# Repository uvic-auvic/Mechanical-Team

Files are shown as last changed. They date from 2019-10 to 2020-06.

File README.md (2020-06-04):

# AUVIC Mechanical Repository

Welcome to the mechanical team. One rule: do not push directly into master. Please talk with the lead if you dont understand why.

## Getting started (bottom up)

We use solidworks prolifically in this university. I will assume everyone is using a windows machine. Before continuing, please make a [github](https://github.com/) account.  

- Go to [gitforwindows.org](https://gitforwindows.org/) to download git. Follow instalation guidelines but enable "use git from the command line"
- After completing the installation, open CMD (shortcut: WIN+R , enter 'cmd') and enter these two commands
    - git config --global user.name "*your name*"
    - git config --global user.email "*github email*"
- Next we want to clone the repository:
    - Open cmd and in your user directory, type "*mkdir auvic*"
    - Type "cd auvic"
    - In the mechanical team repository, click the green "clone or download" button and copy the address.
    - Type "git clone https://github.com/uvic-auvic/Mechanical-Team.git *name_of_folder*"

You are ready to go (but not really).

## Really getting started

Before you rush into a project there is one major rule that must be followed at all times:

**Do not push directly into master**

Now that you have a copy of the repository on your device, it is yours. Nobody but you can edit it's contents. But there is a procedure that must be followed before beginning and finishing a project, which is branching.

### What is branching?

Branching is the way how multiple people can be working in one project and not impede one another. If everyone worked in a single branch, you will find some files moved, disabled, or deleted everytime someone pushes to the remote repo. In large projects, this makes work much more difficult. This is why clever people created branching, basically having two "timelines" of the same project that merge once the project manager accepts the changes.

In the case of no branching, say Evan was working on the main enclosure assembly of the submarine and decided to use a part that Peyton originally made for the frame. At first everything is fine, but after a little while later Peyton finds the frame design is fundamentally incorrect and deletes all his files and update the remote repo. Evan, seeing the repo being updated, pulls a fresh copy. All of sudden, parts randomly disapeared from his assembly. After several hours of checking the folders for the missing parts with no luck, he decides to remake them ground up; wasting time and energy. 

Using branching, Peyton and evan would be working on their own branches, while the master branch stays clean and only contains reviewed and approved parts. Any pushes Peyton makes would only affect his branch and Evan can complete his work safely.

### How to switch branches

To switch into different branches, you will need to use the keyword *checkout*. First check the current list of branches and choose the one you want to download locally. See the list of common git commands below to download and switch branches.

- Check the current list of branches: "git branch -a"  
- Download a remote branch: "git checkout *name_of_branch*"
- To peek at the contents of a branch: "git checkout origin/*name_of_branch*"
- To make your own branch and checkout into it: "git checkout -b *name_of_branch*"
    - Creating a local branch and pushing it into a remote repository is a more involved and much more than I expect from a mechanical student. I prefer you create the branches on the web client rather than on the command line, if needed.

After switching into your branch, you can now begin.

## Saving your work on the local repository

There are two ways you can save your work: committing and stashing. There isnt really any rules following commiting and stashing, but my only concern is dont *commit* an incomplete part. If for any reason you need to switch branches to work on another project, you should *stash* your work. A commit is basically a save point, in case you mess up bad, you want to be able to return to your last working copy of your project. An example where you would stash rather than commit is if you didnt finish building a part and you needed to switch projects.

You can stash multiple time and also on different branches. Here are a list of some commands:

- To stash your work: "git stash"
- To view all your stashes: "git stash list"
- To retrieve your stash: "git stash apply"
- to retrieve a specific stash: 
    - Get its name with "git stash list"
    - use "git stash apply *stash@{2}*"
- To commit your work: 
    - navigate to the repo
    - git add *
    - git commit -m "*enter message here*"
    **NOTE:** files need to be "Staged" to be commited by using the *add* command. 

## Pushing your work to the rmeote repository/branch

After you commited your work. Use the command: "git push" and that is it.

## After completing your assembly

Use the command: "git pull-request" for the lead to review your assembly. 
Now repeat.

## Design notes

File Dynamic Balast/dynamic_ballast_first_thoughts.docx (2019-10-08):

# Dynamic Ballast - Initial Thoughts

Bob Noakes
October 2, 2019

In order to reduce the constant vertical thrusting requirement for the UAV, it was proposed that a dynamic ballast system be conceptualized/designed. This would allow the vessel to submerge and surface by changing the ballast tank between air and water fill.

# Functional Requirements

- Submerge at the beginning of the run from surface to 10ft (3m) below water level
- Complete submerge operation in ??? seconds
- Remain submerged throughout the 30 minute trial period
- Surface at the end of the trial period
- Complete surfacing operation in ??? seconds
- Fit inside/on the submarine vessel and not interfere with the vessel operation
- Not pose a safety or damage risk from rupturing
- Others?

# Theory

The vessel size and mass should be designed to be approximately neutrally buoyant with the ballast tanks ~50% filled with water. The main variable affecting the magnitude of the submerging/surfacing force is the volume of the ballast tank.

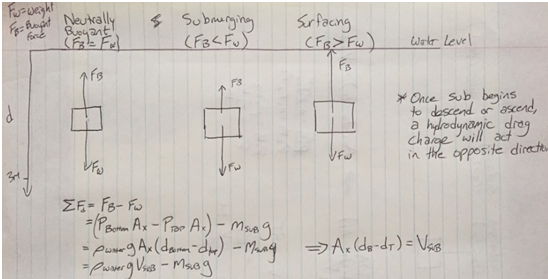
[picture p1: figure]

# Proposed operation

The buoyant force is equal to the weight of the displaced water. The system must be smart enough to fill up enough ballast to submerge at the desired speed, then partially purge to attain neutral buoyancy once the vessel reaches the target depth.

Surfacing is initiated by further or complete purging of water from the ballast tank. There must be enough pressure in the air tank to overcome hydrostatic pressure at the target depth and purge the water volume with a safety factor.

Here is a sample calculation with theoretical values. A 3L ballast tank provides a ~30N force window (15 for submerging, 15 for surfacing).

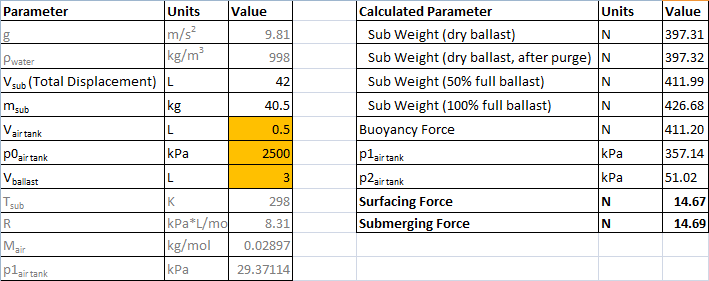
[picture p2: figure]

# Actions

- Find out what the hydrodynamic drag is at the required submerging/surfacing speed, determine size of ballast tankrequired
- Figure out what tank is the best option to contain the pressurized air
- Design a valve arrangement and control system
- Fit the tank into the vessel design

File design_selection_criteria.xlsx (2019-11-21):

Feature | Sub-Feature | Weight | Design 1 Score | Design 2 Score | Design 3 Score
Gate navigation | Passes through | 100
 | Maintains fixed heading | 150
 | Coin flip | 300
 | Pass through 60% Section | 200
 | Pass through 40% Section | 400
 | Style | 800
Picking up objects | Crucifix | 400
 | Garlic | 400
Follows "path" |  | 200
Slaying vampires | Any | 300
 | Called | 300
Drop garlic | Open | 1400
 | Closed | 600
 | Move Arm | 400
Stake through heart | open oval, cover oval, Sm Heart | 2400
 | move lever | 400
 | Bonus: cover oval, Sm heart | 500
Expose to sunlight | Surface in area | 1000
 | surface with object
 | open coffin | 400
 | drop pickup | 200
Random Pinger first task |  | 500
Random Pinger second task |  | 1500
Inter vehicle communication |  | 1000
Minutes Leftover |  | 100
Website |  | 50
Technical Merit |  | 150
Written Style |  | 50
Static Judging - capability |  | 100
Creativity |  | 100
Team Uniform |  | 10
Team Video |  | 50
Pre-qualification |  | 100
Discretionary static points |  | 40
TOTALS

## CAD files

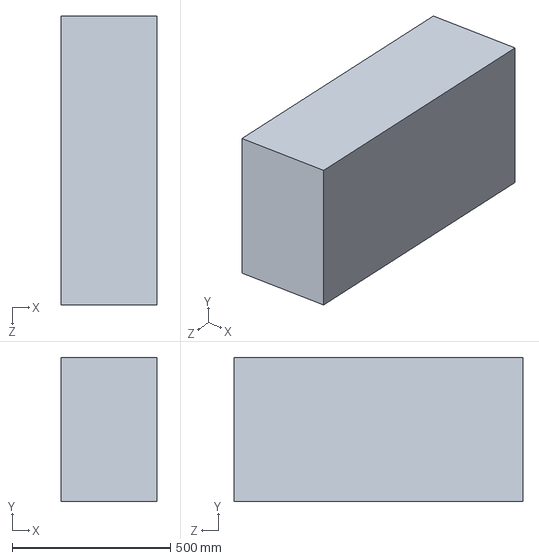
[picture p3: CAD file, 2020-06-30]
frame/demonstration/PART_MODEL_mainenclosure.SLDPRT
304.8 x 457.2 x 914.4 mm

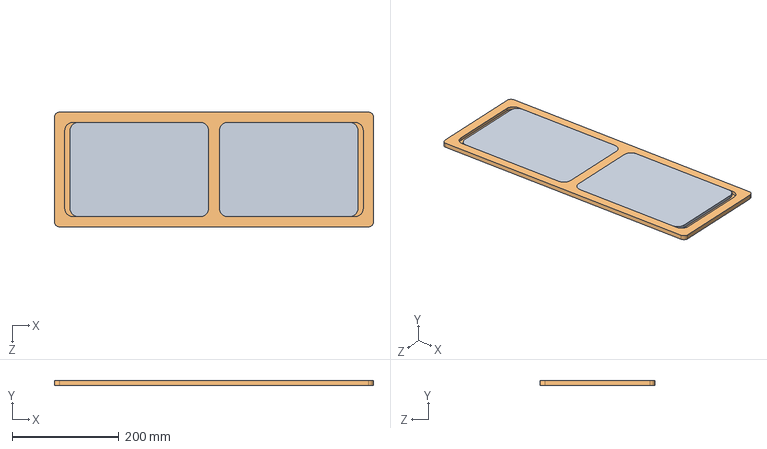
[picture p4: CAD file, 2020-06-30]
lobsta_concept_CAD/auv_assemblies/shell_rect_assembly.sldasm
599.0 x 9.00 x 215.4 mm
Lid_window x 2
lid_rectangular

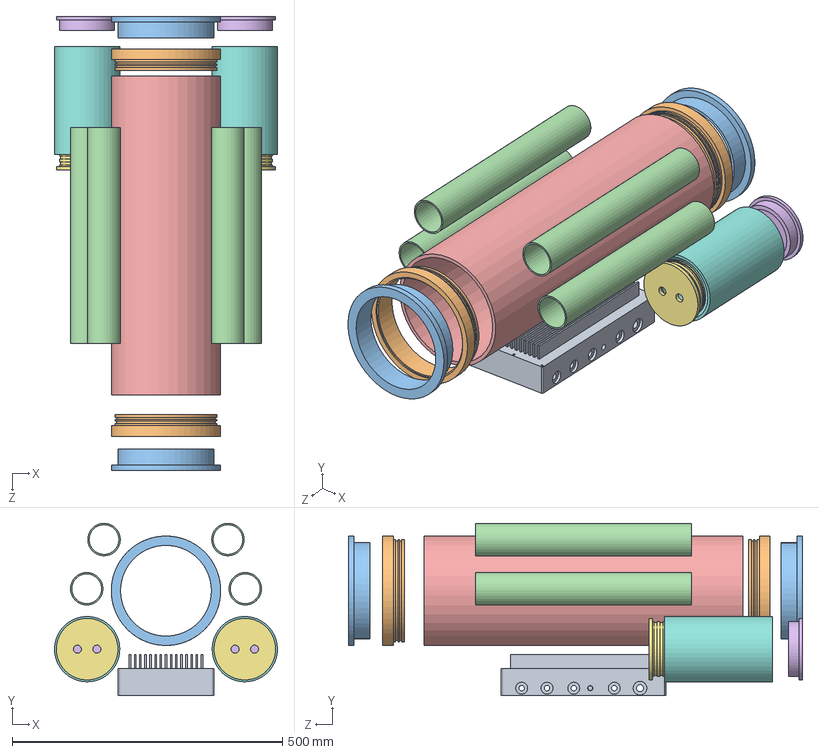
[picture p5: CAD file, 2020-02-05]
lobsta_concept_CAD/shell_assembly.SLDASM
412.7 x 319.1 x 840.6 mm
PN220301_Rev3 - Main
end_housing x 2
end_cap x 2
Pontoon x 4
inner_main_shell
cap_fixed x 2
cap_remove x 2
housing x 2

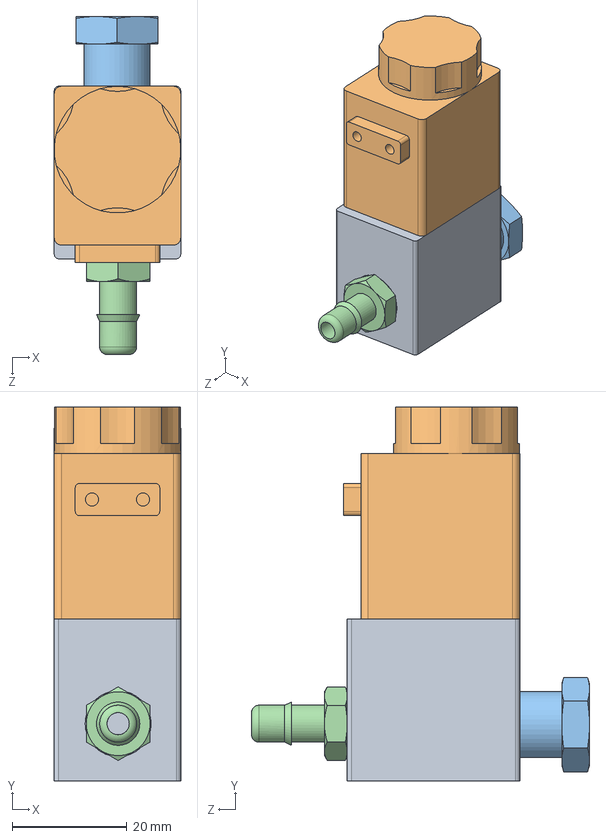
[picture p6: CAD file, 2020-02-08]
lobsta_concept_CAD/solenoid_valve/Solenoid Valve Assembly REV1.SLDPRT.SLDASM
22.0 x 65.1 x 58.9 mm
Solenoid Valve bottom REV1
Solenoid Valve Top REV1
Brass Adapter
5058K294_ALUMINUM BARBED TUBE FITTING

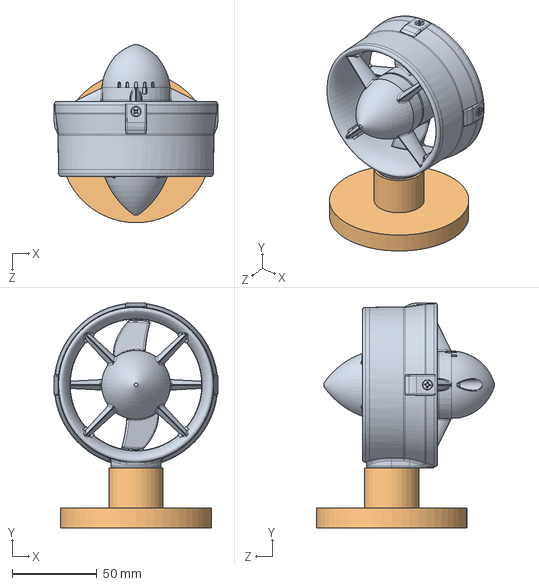
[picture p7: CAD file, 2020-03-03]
lobsta_concept_CAD/thrusters/thruster_assem.SLDASM
96.6 x 132.8 x 105.3 mm
T100-ASM-CW-THRUSTER-R1
thruster_bracket

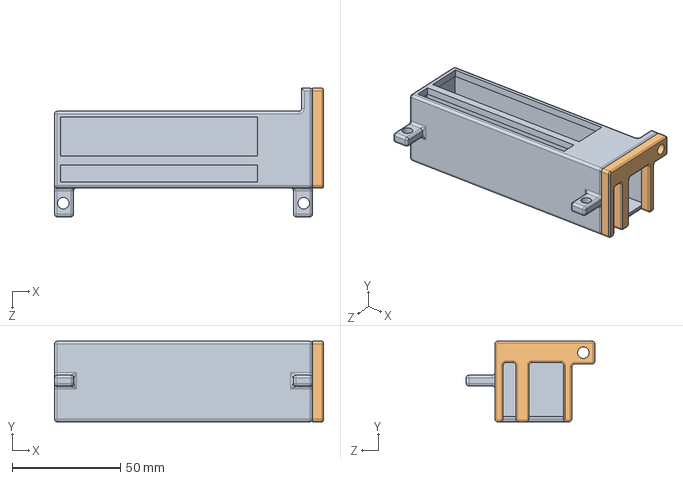
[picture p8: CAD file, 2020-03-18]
lobsta_concept_CAD/usb_hub/USB-holder-assy-v2.SLDASM
124.5 x 37.3 x 59.6 mm
USB-holder-box-v4
USB-holder-cover-v2

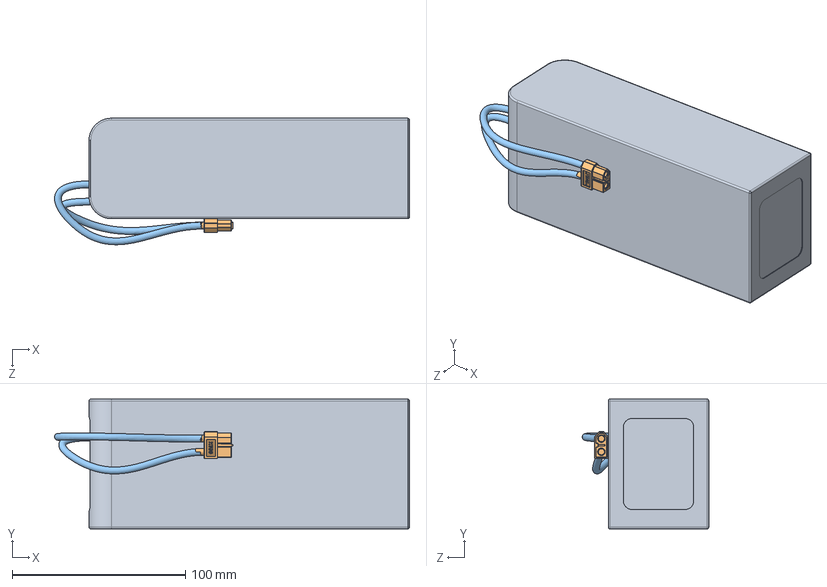
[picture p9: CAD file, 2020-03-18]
lobsta_concept_CAD/battery/Assembly_Multistar_Battery_3000mah.SLDASM
204.9 x 75.0 x 73.1 mm
Multistar_3000mAh_4S_Lipo_Battery
XT60 Buchse
Part3^Assembly_Multistar_Battery_3000mah

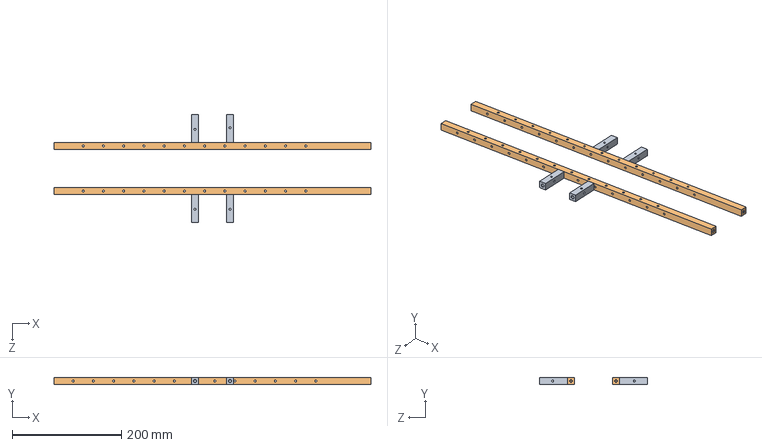
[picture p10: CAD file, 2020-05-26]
lobsta_concept_CAD/frame/frame_assembly.sldasm
581.0 x 12.7 x 197.4 mm
barstock support_short x 4
barstock support_long x 2

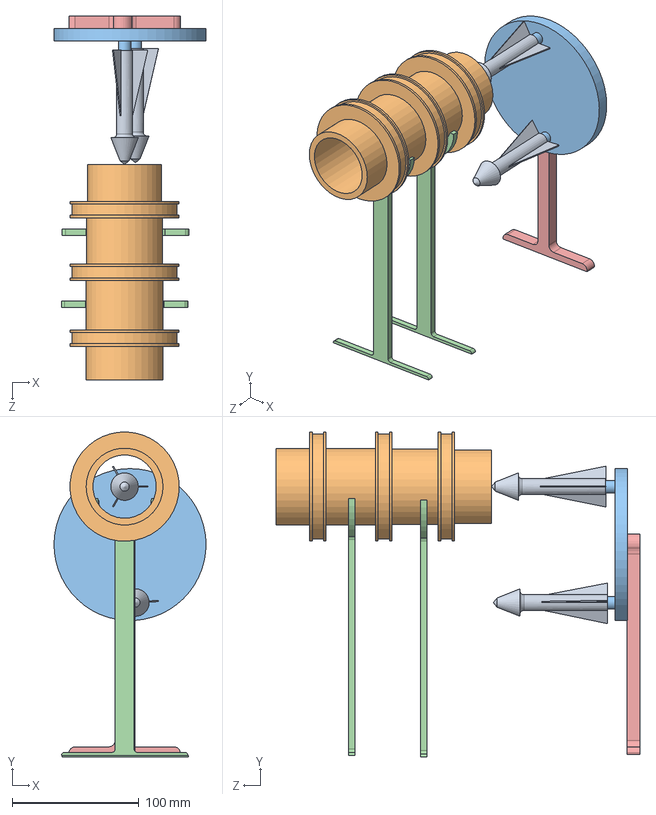
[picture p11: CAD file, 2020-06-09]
Torpedos/Assembly_torpedo-system1.SLDASM
119.9 x 256.6 x 287.0 mm
torpedo x 2
barrel
gattling disk
barrel_stand x 2
gattling_stand

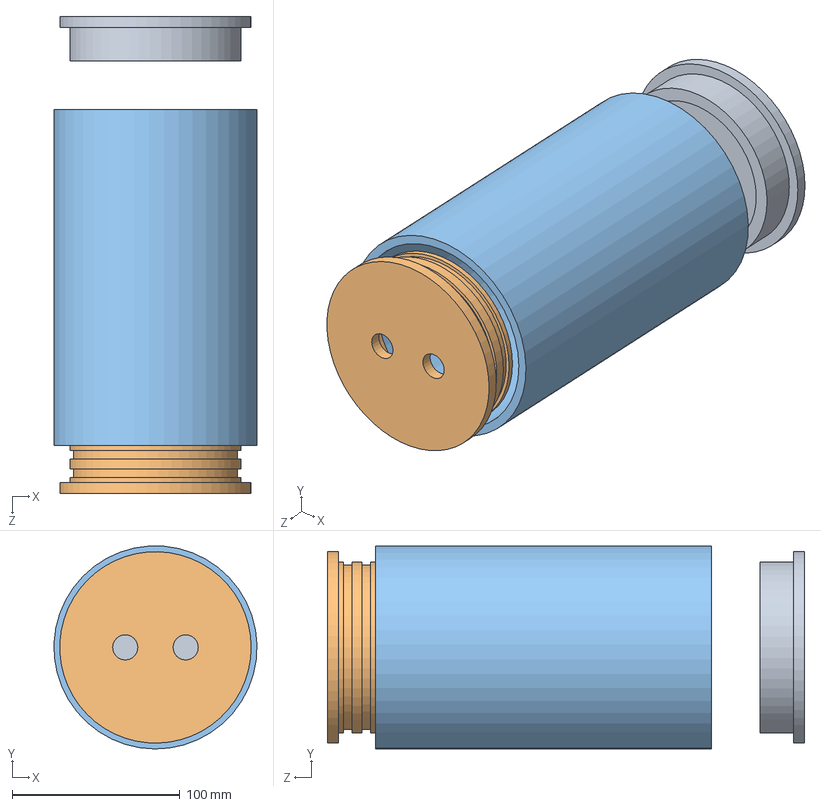
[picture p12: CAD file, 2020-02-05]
lobsta_concept_CAD/battery assembly/battery_assembly1.SLDASM
120.9 x 120.9 x 284.1 mm
cap_fixed
cap_remove
housing

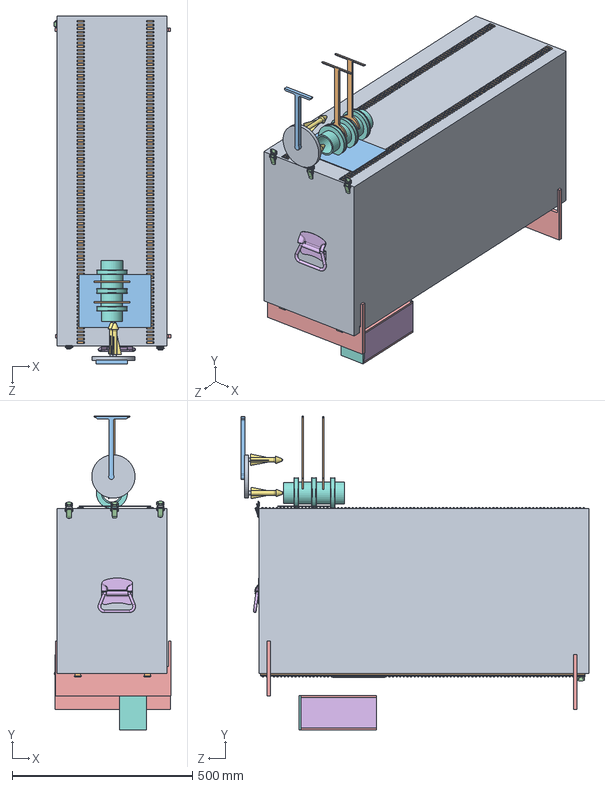
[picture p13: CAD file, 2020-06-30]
frame/demonstration/ASSEM_Frame.SLDASM
323.4 x 870.6 x 963.6 mm
PART_MODEL_mainenclosure
PART_PicRail x 4
PART_PeriphMount x 2
6082A120_DRAW LATCH x 4
stand x 2
TCH-500-1335802
torpedo x 2
barrel
gattling disk
barrel_stand x 2
gattling_stand
AUVIC ArcScrew 1stDraft
Top Bottom cap x 2
Side Plate x 2
BALL x 2
Back Plate

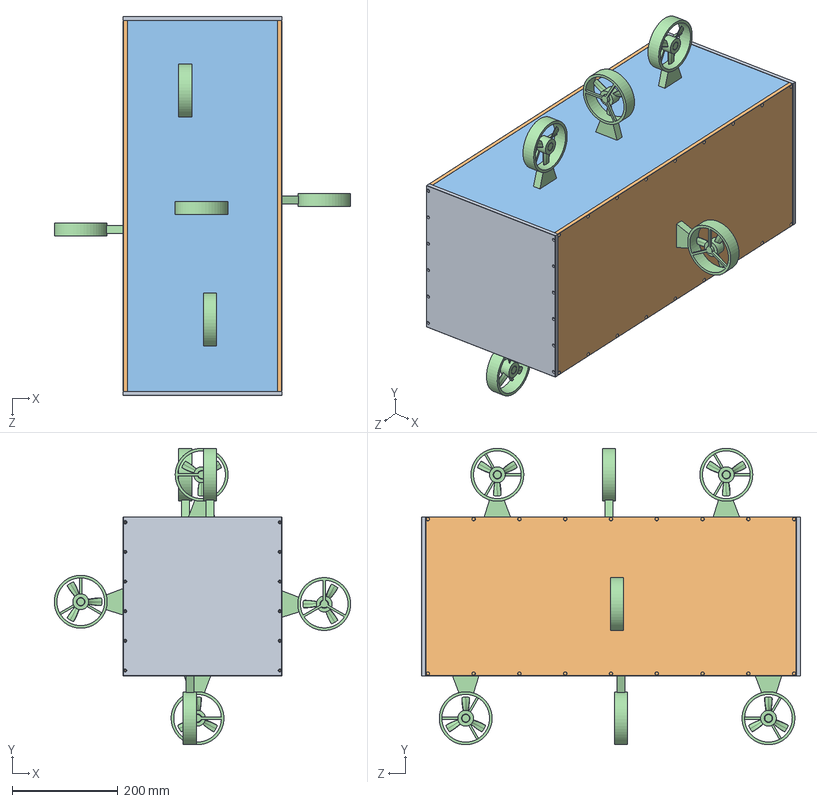
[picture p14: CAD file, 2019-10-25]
Mockup Drawings/square_sub/square_assem.SLDASM
560.0 x 560.0 x 716.0 mm
back_plate x 2
side_plate x 2
top_plate x 2
thruster x 8

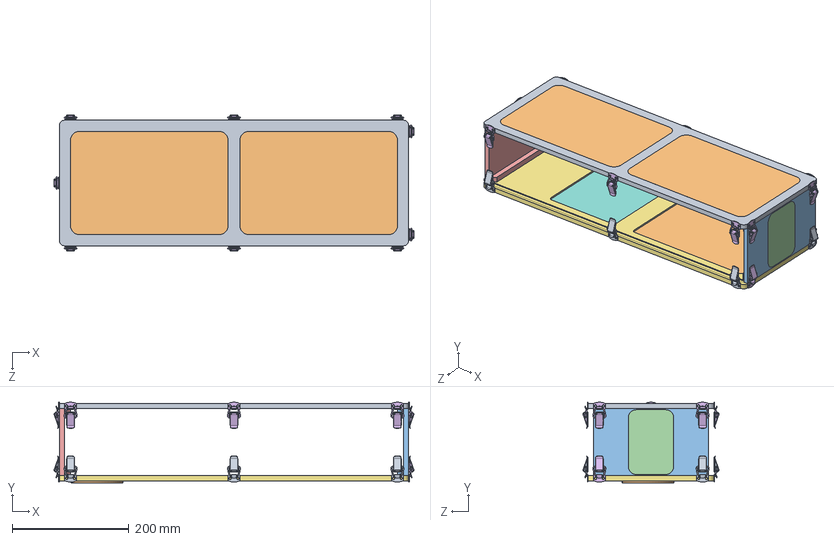
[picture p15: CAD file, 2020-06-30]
lobsta_concept_CAD/auv_assemblies/shell_rectangular_assembly.sldasm
617.2 x 138.3 x 233.6 mm
lid_rectangular
Lid_window x 3
front_plate
front_window_single
rear_plate
6082A120_DRAW LATCH_part x 10
lid_rectangular_bottom
lid_window_bottom_small
Mirror6082A120_DRAW LATCH_part x 8
HydrophoneLasrecut

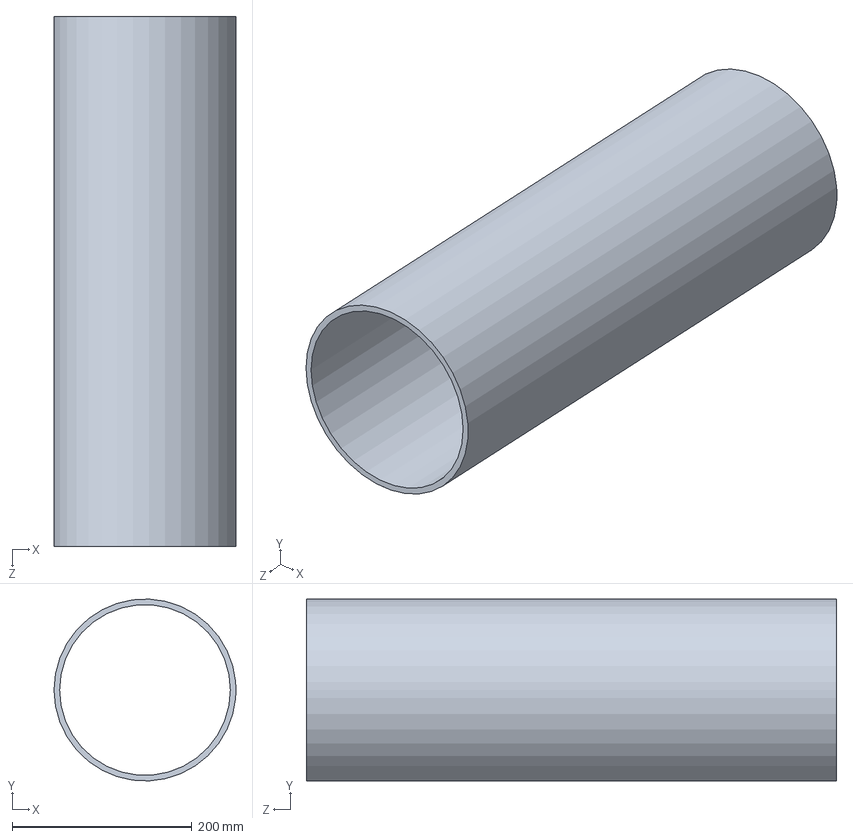
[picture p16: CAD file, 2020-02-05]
lobsta_concept_CAD/inner_main_shell.SLDPRT
202.6 x 202.4 x 590.0 mm

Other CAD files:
lobsta_concept_CAD/frame/frame_rectangular_assembly.sldasm
lobsta_concept_CAD/auv_assemblies/lid_assembly.sldasm
lobsta_concept_CAD/auv_assemblies/top_lid_assembly.sldasm
lobsta_concept_CAD/auv_assemblies/front_plate_assembly.sldasm
Blue-Robotics Mounts/Thruster Front Mount.SLDPRT
Blue-Robotics Mounts/Thruster Mount.SLDPRT
Blue-Robotics Mounts/Thruster Mount.STL
Final Assembly_POLARIS/5972K214_BALL BEARING.SLDPRT
Final Assembly_POLARIS/5972K231_BALL BEARING.SLDPRT
Final Assembly_POLARIS/98543A114_SIDE-MOUNT EXTERNAL RETAINING RING E-STYLE.SLDPRT
Final Assembly_POLARIS/Attachment Detail.SLDPRT
Final Assembly_POLARIS/Carrier.SLDPRT
Final Assembly_POLARIS/Clutch.SLDPRT
Final Assembly_POLARIS/Complete_Assem.SLDASM
Final Assembly_POLARIS/End Cap.SLDPRT
Final Assembly_POLARIS/Hub.SLDPRT
Final Assembly_POLARIS/Hub_bearing_assembly.SLDASM
Final Assembly_POLARIS/Key.SLDPRT
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

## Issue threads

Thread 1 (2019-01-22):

Redo torpedo to be safer

batesandy123, 2019-01-22:
Currently, the torpedo's are made of PVC which when fails will have a violent shrapnel flying failure. Consider switching the material to something that is more safe. Also, keep cost in mind as the current solution is very cheap.

Furthermore, Let's add a safety value that guarantees the pressure is not to high.

Finally, as a last safety is it possible to guarantee a safe failure mode if the value doesn't function correctly

Closed 2019-09-11.

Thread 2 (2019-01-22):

Sub servicing apparatus

struaneamer, 2019-01-22:
Need an apparatus to allow servicing of the sub bottom face

bobcatCA, 2020-02-12:
All 4 of the MECH team members to think of their best design concepts and a rough bill of materials by Feb 18th meeting.

bobcatCA, 2020-03-03:
Chop up and re-assemble A frame
talk to Summer about machining tabs
get T-supports fabricated

bobcatCA, 2020-03-10:
Finished A-frame. Complete attachment points for next week.

Closed 2020-06-08.

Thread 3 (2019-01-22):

Look at removing the center cross bar.

batesandy123, 2019-01-22:
The current cross bar is heavy, and doesn't critically hold the submarine together. I would like to replace this material to be lighter and cheaper.

Also, I want the reed switch to moved lower down the submarine.

Closed 2019-09-17.

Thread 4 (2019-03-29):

Attaching Blue Robotics T100 thrusters

anijjar, 2019-03-29:
The mounting points for the new thrusters do not match our own. Should we make a mounting bracket or drill new holes? I want this inexpensive, but working. If you go the design route Jason, please upload all your files into a folder called "Blue Robotics T100" and push it to a branch called "Blue Robotics T100" to keep the main repo clean.

Closed 2019-07-16.

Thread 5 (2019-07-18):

Upload the Mounting brackets files onto the git

anijjar, 2019-07-18:
Miguel/Jason/Micheal
Please go into the "Blue robotics t100" branch and upload the files needed to print the mounting posts.

Thank you

anijjar, 2019-07-18:
Also make a pull request

Closed 2019-07-19.

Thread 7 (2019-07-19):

Print a set of torpedos

anijjar, 2019-07-19:
we are missing one of the torpedos. We need to get 2 compressed air canister somewhere and 3d print them.

Closed 2019-09-17.

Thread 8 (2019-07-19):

Print Kill switch part (in-housing)

anijjar, 2019-07-19:
Karan is currently redesigning the kill switch. I am fully confident it will work great, however since the kill switch can literally kill our chances to compete. We must bring one copy of the working, tested version.

Task: Locate old kill switch part on the club computer and let aman know so he can find someone to print it out.

Closed 2019-09-11.

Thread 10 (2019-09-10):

Make Grabber Arm

rkeen9, 2019-09-10:

bobcatCA, 2020-02-12:
Terry to spend this week coming up with claw/grabber arm concepts
-Tailor to picking up the "bottles" and moving the lid handle (pincer concept)
-Possibly re-use part of the tri-grabber arm

bobcatCA, 2020-03-10:
-Reverse engineer grabber head
-Make new CAD model for logging 3-claw design
-Make a few concepts for addressing bottle orientation

Closed 2020-06-08.

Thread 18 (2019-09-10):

Ball Dropper Development

rkeen9, 2019-09-10:

bobcatCA, 2020-02-12:
Peyton to get SW 2019 working, research ball dropper designs. Reach out to Poorna to see if there were issues and where to start. Also, Gabe's girlfriend could be a good person to ask (intro from Karan).

bobcatCA, 2020-03-03:
Working on size and shape of screw
Refine size and shape of shell
Refine CAD model
Bob invite Evan to github and look into 3DP

bobcatCA, 2020-03-10:
-Foregoing magnetic coupling
-Pursuing DC brushless motor submerged design
-Finalize CAD model and send to Bob for 3DP

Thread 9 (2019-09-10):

Test Torpedoes

rkeen9, 2019-09-10:
First: remove one of the torpedos from the submarine.
second: find a bicycle pump to borrow to measure air pressure. then proceed to fire them in the fish tank.

anijjar, 2019-11-26:
## update
I brought a bike pump from my home and the torpedos have been removed. the pump requires car to activate however. so we should get a car adapter to wall plugin or something. we can test in the fish tank for now.

Closed 2020-06-08.

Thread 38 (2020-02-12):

Develop new torpedo concept

bobcatCA, 2020-02-12:
Possibly for 2021 sub but also may need to develop for RS 2020

bobcatCA, 2020-02-12:
Karan to develop preliminary CAD model and start looking into prototyping for Feb 18th meeting.

bobcatCA, 2020-03-03:
CAD full assembly
resolve locking mechanism

bobcatCA, 2020-03-10:
-CAD model complete, update as necessary
-Design means of magnetic coupling across barrier
-Begin prototyping
-Address power needs

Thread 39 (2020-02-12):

Frame concepts

bobcatCA, 2020-02-12:
Everyone look at the free-floating CAD assembly and come up with one good concept for how to hold it all together.
-Needs to be hydrodynamic to improve stability
-Needs to be lighter than the current design

Closed 2020-06-08.

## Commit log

2019-07-18 Adding Thruster STL and SolidWorks File
    [Thruster Mount.SLDPRT, Thruster Mount.STL]
2019-07-21 Kill switch Project
    FInished. all thats left is to wait for magnets and 3d print
    [kill switch bottom.SLDPRT, top key v4.SLDPRT]
2019-07-23 front and back mounts
    [Thruster Front Mount.SLDPRT]
2019-10-08 Dynamic Balast Calculator
    [buoyancy_calculator.xlsx]
2019-10-25 uploading drawings and assembly for prism mockup design option
    [back_plate.SLDPRT, side_plate.SLDPRT, square_assem.SLDASM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]
2020-01-23 uploading folder for initial lobster sub concept
    [inner_main_shell.SLDPRT]
2020-01-28 1st versions of hull sealing cap, frame and outer shell
    [cap.SLDPRT, flat_frame.SLDPRT, outer_main_shell.SLDPRT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]
2020-01-28 finished flat portion of frame
    [flat_frame.SLDPRT]
2020-01-29 assembled for the first thime the inner/outer shells, pontoons, and cap
    [Pontoon.SLDPRT, cap.SLDPRT, inner_main_shell.SLDPRT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]
2020-01-29 uploading first motor shell and pontoon
    [Motor Shell.SLDPRT, Pontoon.SLDPRT]
2020-02-05 first battery housing assembly
    [battery_assembly1.SLDASM, cap_fixed.SLDPRT, cap_remove.SLDPRT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]
2020-02-05 changed the assembly to reflect new design. No concentric ballast anymore because the 10in pipe was too expensive. also made changes to the pontoon and cap.
    [Motor Shell.SLDPRT, PN220301_Rev3 - Main.SLDPRT, PN220303_Rev2 - Lid Lexan.SLDASM.SLDPRT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]
2020-02-05 added 2 battery assemblies to the master assembly
    [shell_assembly.SLDASM]
2020-02-08 added more files to the assembly, including NVIDIA board and internal frame
    [220111 - barstock support.SLDPRT, 220112 - camera mounting plate.SLDPRT, Solenoid Bracket REV2.SLDPRT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]
2020-03-03 added complete motor assembly from previous sub. Imported thruster CAD files
    [220300 - Motor Housing Final Assembly.SLDASM, 220302 - Motor Housing LID ALUMINUM REV2.SLDASM.SLDPRT, 220303 - Motor Housing LID ACRYLIC REV2.SLDASM.SLDPRT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]
2020-03-10 Added NVIDIA Jetson developer kit, motor control board, and batteries
    [Assembly_Multistar_Battery_3000mah.SLDASM, Multistar_3000mAh_4S_Lipo_Battery.SLDPRT, XT60 Buchse.SLDPRT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]
2020-03-10 added USB holder, bottom camera, forward camera, and hydrophone files
    [Bottom Facing Camera Adapter.SLDPRT, Bottom Facing Camera Mount.SLDPRT, Bottom Facing Camera Mount.STL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]
2020-03-10 Added ball dropper parts
    [AUVIC ArcScrew 1stDraft.SLDPRT, AUVIC ArcScrew Prototype.STL, AUVic ArcScrew POC.SLDPRT]
2020-03-11 refined electronics assembly to look better
    [barstock support_long.SLDPRT]
2020-03-18 made new Power Board model, made panel windows and top gasket groove. Moved components around - may still need to lengthen in order to keep battery packs centered
    [1889A430_DRAW LATCH.SLDPRT, Assembly_Multistar_Battery_3000mah.SLDASM, Lid_window.sldprt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]
2020-03-20 did a lot of work on the lid and body dimensions. Re-convigured to get 8 penetrators for motors, plus others for auxiliaries. Aluminium back to allow for more penetrators. Added Hydrophone bracket.
    [1889A430_DRAW LATCH.SLDPRT, 220111 - barstock support.SLDPRT, 6082A120_DRAW LATCH_part.SLDPRT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]
2020-05-26 udded changes from kraken
    [1889A430_DRAW LATCH.SLDPRT, 220111 - barstock support.SLDPRT, 6082A120_DRAW LATCH.SLDPRT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]
2020-06-09 inital concept torpedo assembly
    [1889A430_DRAW LATCH.SLDPRT, 6082A120_DRAW LATCH.SLDPRT, 6082A120_DRAW LATCH_part.SLDPRT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]
2020-06-09 Ball Dropper Basic Assembly
    [AUVIC ArcScrew 1stDraft.SLDPRT, ArcScrew_Assembly.SLDASM, BALL.SLDPRT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]
2020-06-30 added polaris files
    [5972K214_BALL BEARING.SLDPRT, 5972K231_BALL BEARING.SLDPRT, 6082A120_DRAW LATCH.SLDPRT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]
